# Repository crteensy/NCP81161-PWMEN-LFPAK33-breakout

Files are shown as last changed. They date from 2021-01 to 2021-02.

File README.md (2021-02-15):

# NCP81161-PWMEN-LFPAK33-breakout
Breakout board for NCP81161 gate drivers with PWM and EN inputs and FETs in LFPAK33 like the PSMN1R8-30MLH

## First test successful
The board was tested with an

- STM32G071 (breakout board here: https://github.com/crteensy/STM32G071GBU6_breakout)
- running an experimental branch of AM32, PWM/EN target
- DShot input through a Mamba F405 Mini
- Motor: Mamba 1408 4000KV
- PSU set to 5V, 500 mA current limit

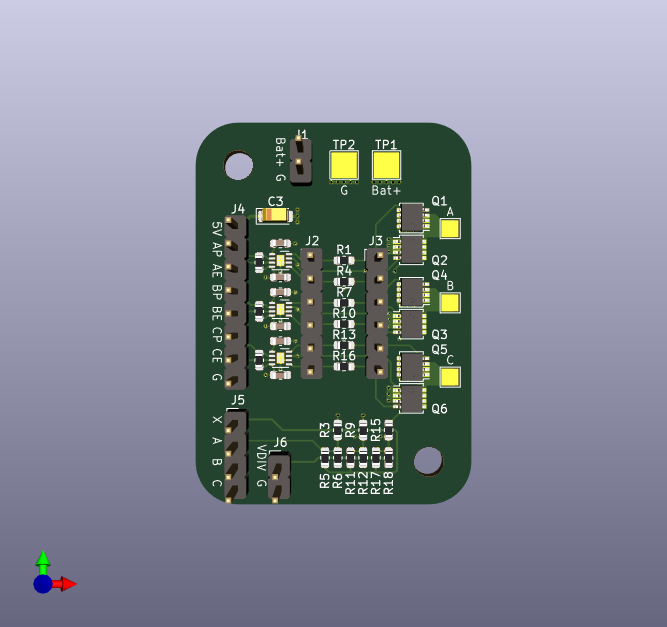
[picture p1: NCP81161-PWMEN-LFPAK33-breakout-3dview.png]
3D view


This breakout board is designed to facilitate testing of PWM/EN-type firmware on e.g. the STM32G071GBU6 (see here for a matching MCU breakout board: https://github.com/crteensy/STM32G071GBU6_breakout)

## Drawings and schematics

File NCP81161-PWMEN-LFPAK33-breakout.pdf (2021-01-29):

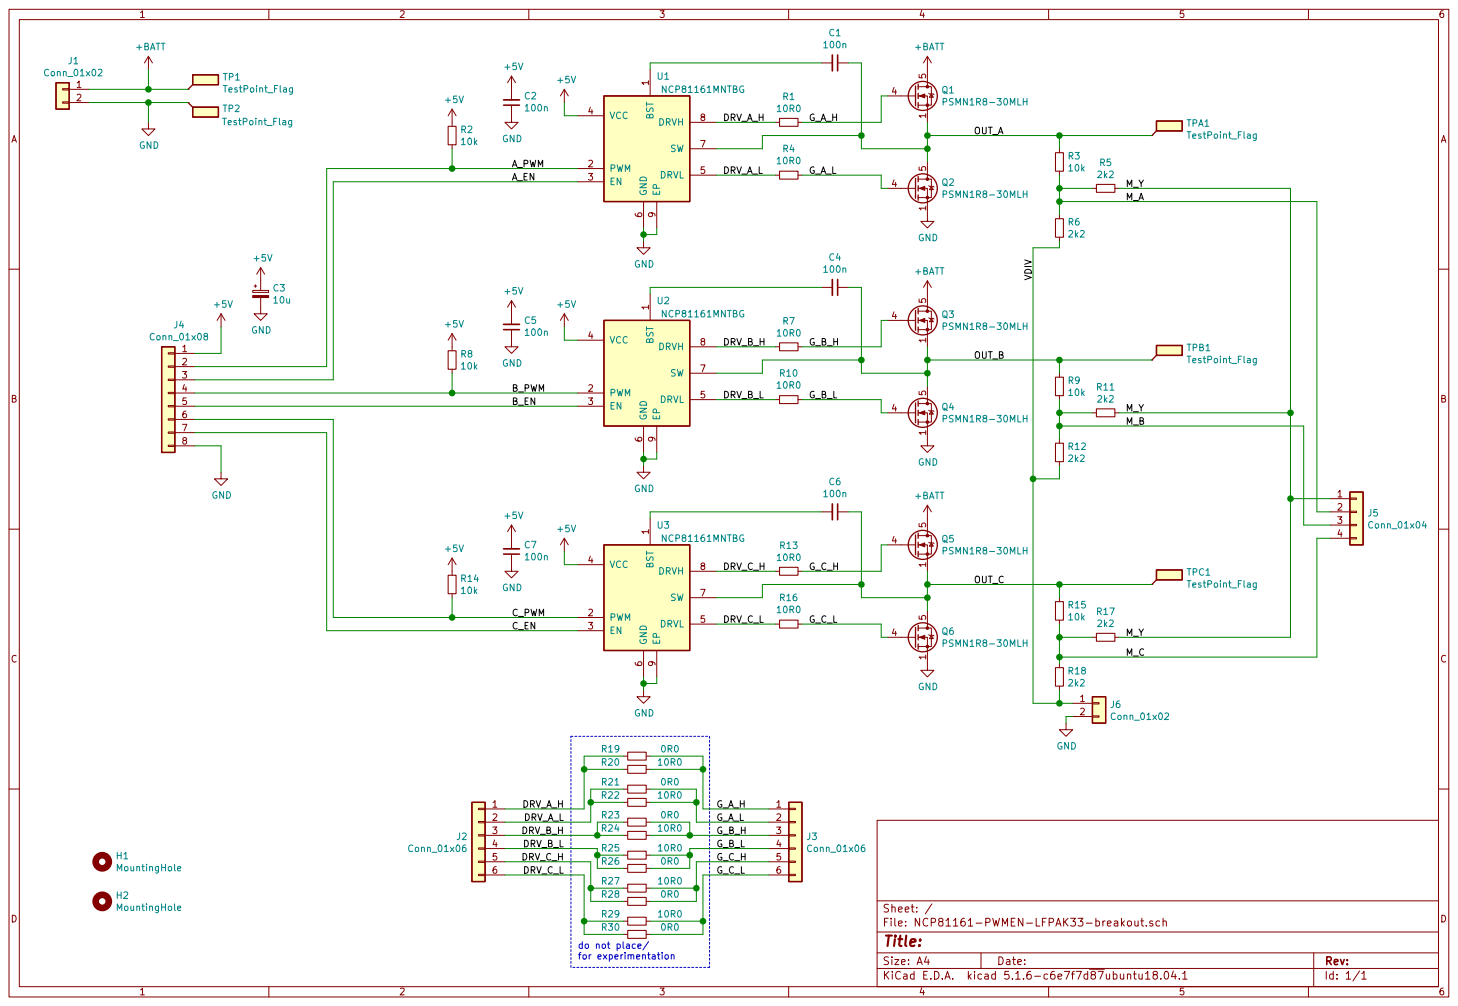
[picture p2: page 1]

Id: 1/1 Title: File: NCP81161-PWMEN-LFPAK33-breakout.sch Sheet: / R14

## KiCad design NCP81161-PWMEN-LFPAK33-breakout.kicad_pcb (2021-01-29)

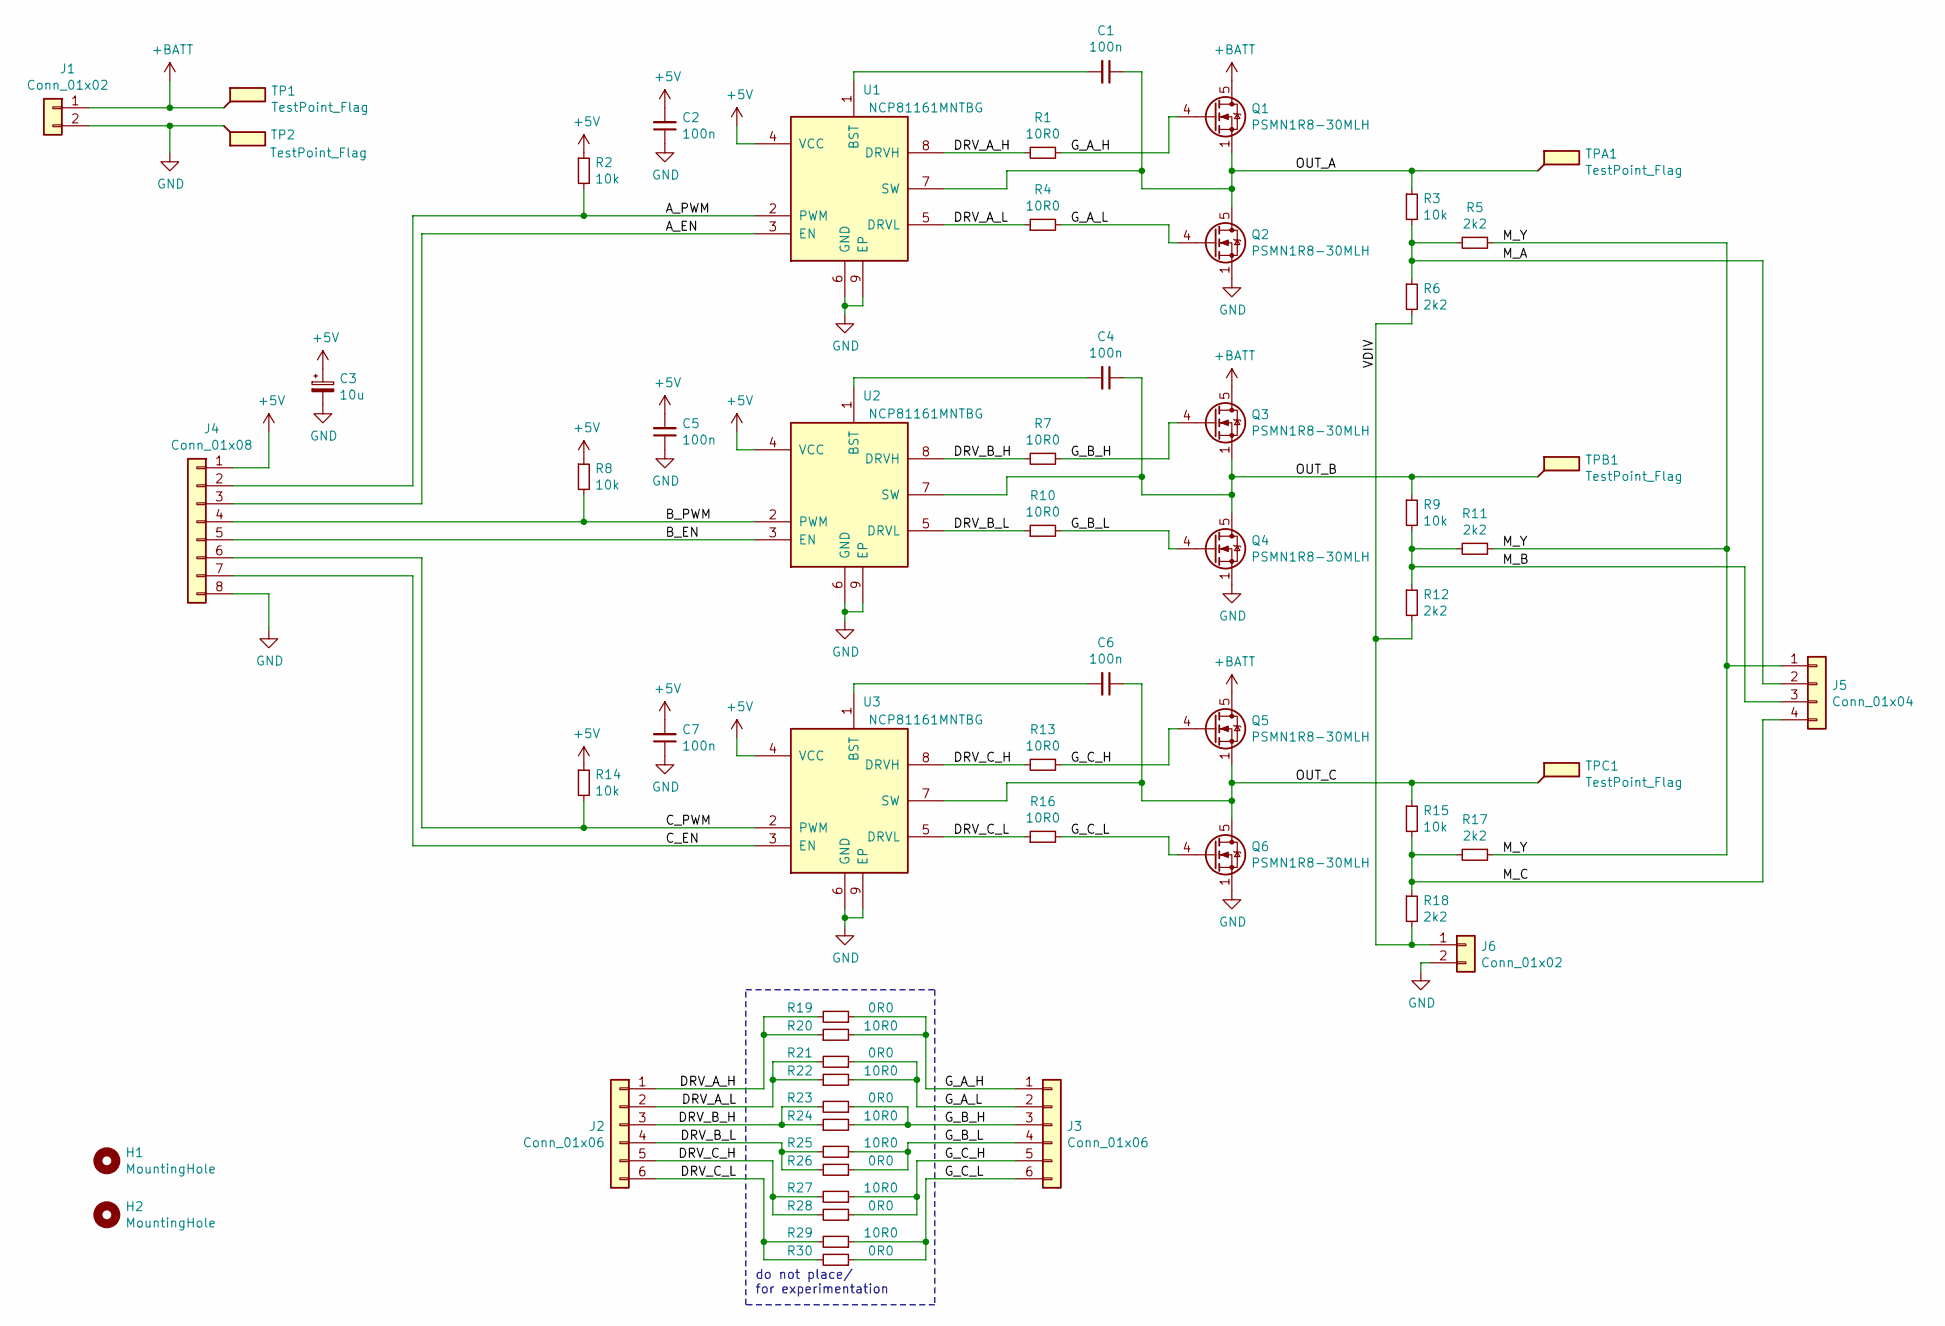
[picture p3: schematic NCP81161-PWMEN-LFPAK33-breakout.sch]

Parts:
C1, C2, C4, C5, C6, C7: 100n; C_0603_1608Metric
C3: 10u; CP_EIA-3216-18_Kemet-A
H1, H2: MountingHole; MountingHole_3.5mm
J1, J6: Conn_01x02; PinHeader_1x02_P2.54mm_Vertical
J2, J3: Conn_01x06; PinHeader_1x06_P2.54mm_Vertical
J4: Conn_01x08; PinHeader_1x08_P2.54mm_Vertical
J5: Conn_01x04; PinHeader_1x04_P2.54mm_Vertical
Q1, Q2, Q3, Q4, Q5, Q6: PSMN1R8-30MLH; LFPAK33
R1, R4, R7, R10, R13, R16, R20, R22, R24, R25, R27, R29: 10R0; R_0603_1608Metric
R2, R3, R8, R9, R14, R15: 10k; R_0603_1608Metric
R5, R6, R11, R12, R17, R18: 2k2; R_0603_1608Metric
R19, R21, R23, R26, R28, R30: 0R0; R_0603_1608Metric
TP1, TP2: TestPoint_Flag; TestPoint_Pad_3.0x3.0mm
TPA1: TestPoint_Flag; TestPoint_Pad_2.0x2.0mm
TPB1: TestPoint_Flag; TestPoint_Pad_2.0x2.0mm
TPC1: TestPoint_Flag; TestPoint_Pad_2.0x2.0mm
U1, U2, U3: NCP81161MNTBG; DFN-8-1EP_2x2mm_P0.5mm_EP0.9x1.3mm

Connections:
+5V: C2.2, C3.1, C5.2, C7.2, J4.1, R2.1, R8.1, R14.1, U1.4 (VCC), U2.4 (VCC), U3.4 (VCC)
+BATT: J1.1, Q1.5 (D), Q3.5 (D), Q5.5 (D), TP1.1
/A_EN: J4.3, U1.3 (EN)
/A_PWM: J4.2, R2.2, U1.2 (PWM)
/B_EN: J4.5, U2.3 (EN)
/B_PWM: J4.4, R8.2, U2.2 (PWM)
/C_EN: J4.7, U3.3 (EN)
/C_PWM: J4.6, R14.2, U3.2 (PWM)
/DRV_A_H: J2.1, R1.2, R19.2, R20.1, U1.8 (DRVH)
/DRV_A_L: J2.2, R4.1, R21.2, R22.1, U1.5 (DRVL)
/DRV_B_H: J2.3, R7.2, R23.2, R24.1, U2.8 (DRVH)
/DRV_B_L: J2.4, R10.1, R25.2, R26.2, U2.5 (DRVL)
/DRV_C_H: J2.5, R13.2, R27.2, R28.2, U3.8 (DRVH)
/DRV_C_L: J2.6, R16.1, R29.2, R30.2, U3.5 (DRVL)
/G_A_H: J3.1, Q1.4 (G), R1.1, R19.1, R20.2
/G_A_L: J3.2, Q2.4 (G), R4.2, R21.1, R22.2
/G_B_H: J3.3, Q3.4 (G), R7.1, R23.1, R24.2
/G_B_L: J3.4, Q4.4 (G), R10.2, R25.1, R26.1
/G_C_H: J3.5, Q5.4 (G), R13.1, R27.1, R28.1
/G_C_L: J3.6, Q6.4 (G), R16.2, R29.1, R30.1
/M_A: J5.2, R3.2, R5.2, R6.1
/M_B: J5.3, R9.2, R11.2, R12.1
/M_C: J5.4, R15.2, R17.2, R18.1
/M_Y: J5.1, R5.1, R11.1, R17.1
/OUT_A: C1.1, Q1.1 (S), Q1.2 (S), Q1.3 (S), Q2.5 (D), R3.1, TPA1.1, U1.7 (SW)
/OUT_B: C4.1, Q3.1 (S), Q3.2 (S), Q3.3 (S), Q4.5 (D), R9.1, TPB1.1, U2.7 (SW)
/OUT_C: C6.1, Q5.1 (S), Q5.2 (S), Q5.3 (S), Q6.5 (D), R15.1, TPC1.1, U3.7 (SW)
/VDIV: J6.1, R6.2, R12.2, R18.2
GND: C2.1, C3.2, C5.1, C7.1, J1.2, J4.8, J6.2, Q2.1 (S), Q2.2 (S), Q2.3 (S), Q4.1 (S), Q4.2 (S), Q4.3 (S), Q6.1 (S), Q6.2 (S), Q6.3 (S), TP2.1, U1.6 (GND), U1.9 (EP), U2.6 (GND), U2.9 (EP), U3.6 (GND), U3.9 (EP)
unnamed: C1.2, U1.1 (BST)
unnamed: C4.2, U2.1 (BST)
unnamed: C6.2, U3.1 (BST)

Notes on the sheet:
do not place/ for experimentation

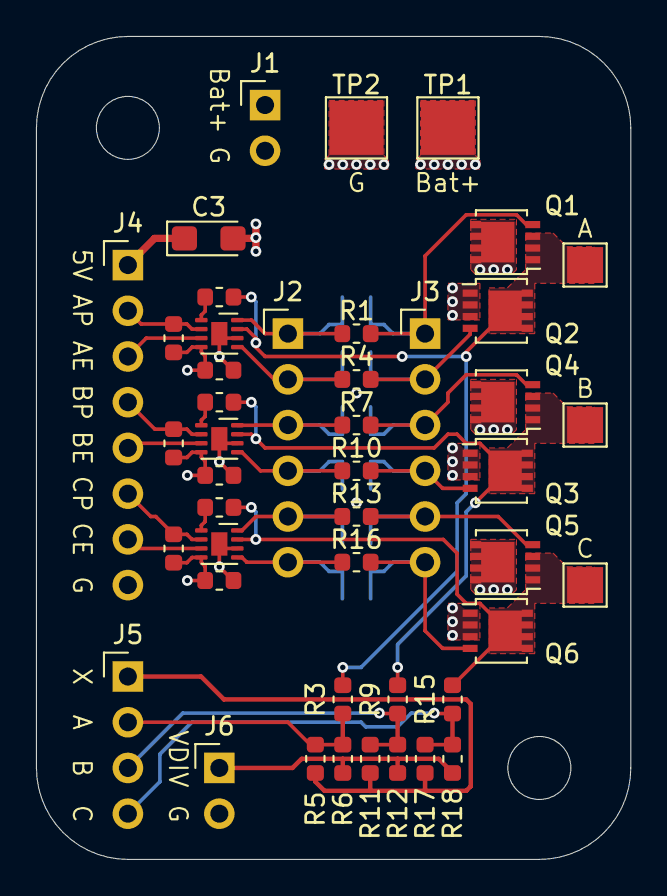
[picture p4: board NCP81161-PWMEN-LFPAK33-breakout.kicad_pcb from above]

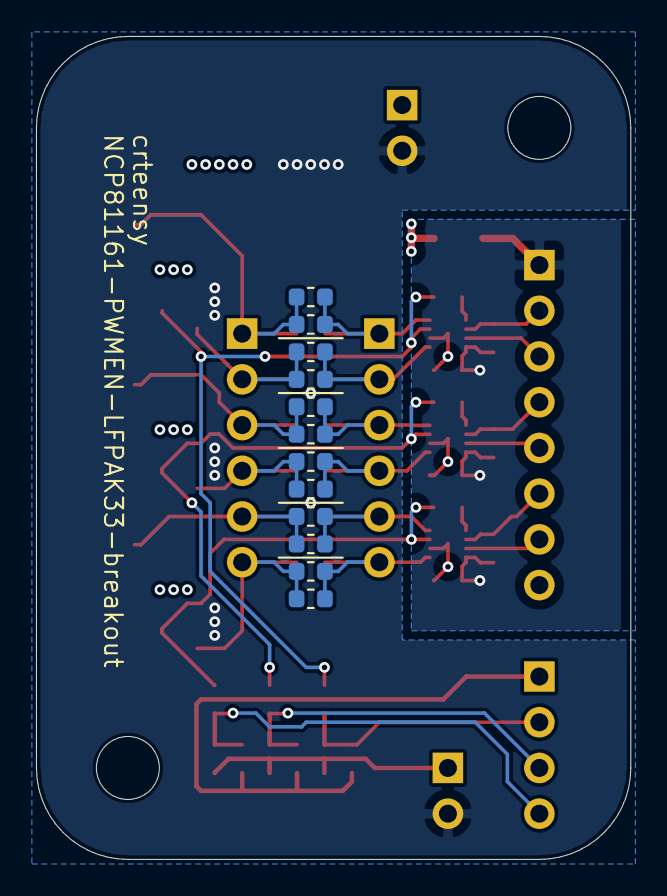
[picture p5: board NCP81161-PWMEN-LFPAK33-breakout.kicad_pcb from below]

Board: 4 copper layers, 33.0 x 45.7 mm, 59 parts (12 on the bottom side), 32 nets.
